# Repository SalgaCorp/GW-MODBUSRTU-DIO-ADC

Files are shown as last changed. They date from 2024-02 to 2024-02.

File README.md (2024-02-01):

GW MODBUS RTU ADC DIGITAL InOut: Open Source

Image of the GW or Node with ESP32 from LILYGO.







View design attachments:

Information document in Spanish

[DOCUMENTO_INFORMATIVO_GATEWAY_MODBUS_v1_06122023.pdf](https://github.com/SalgaCorp/GW-MODBUSRTU-DIO-ADC/files/14130991/DOCUMENTO_INFORMATIVO_GATEWAY_MODBUS_v1_06122023.pdf)

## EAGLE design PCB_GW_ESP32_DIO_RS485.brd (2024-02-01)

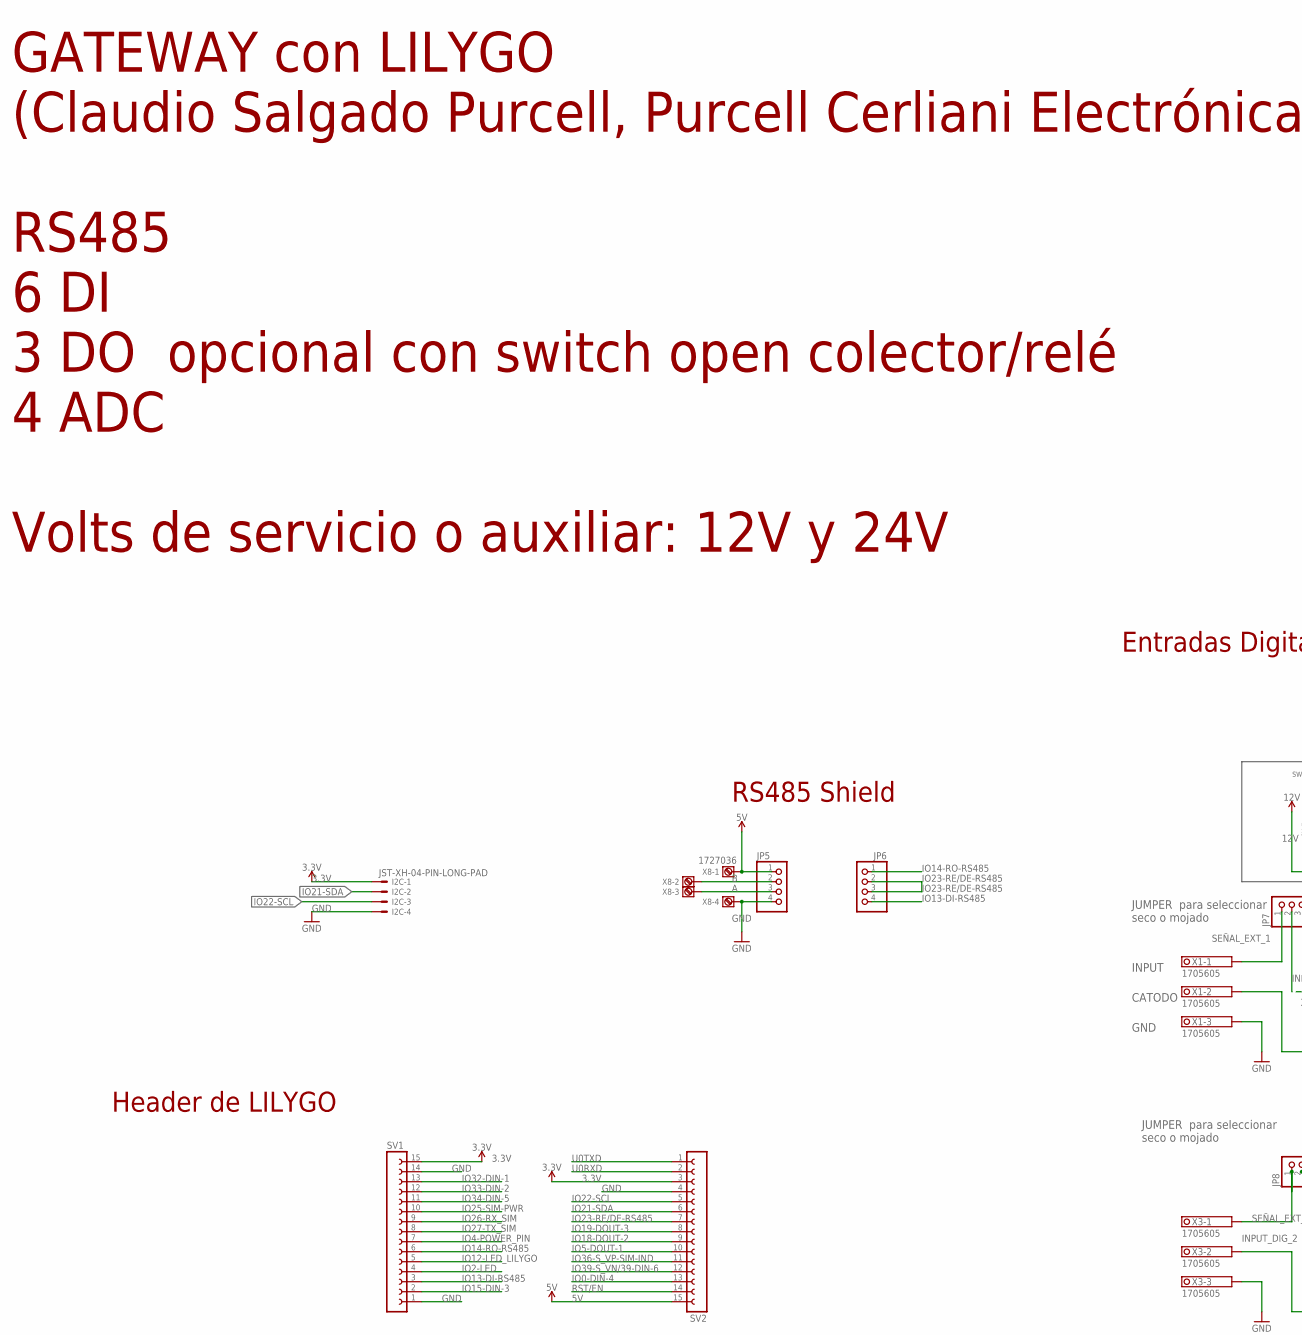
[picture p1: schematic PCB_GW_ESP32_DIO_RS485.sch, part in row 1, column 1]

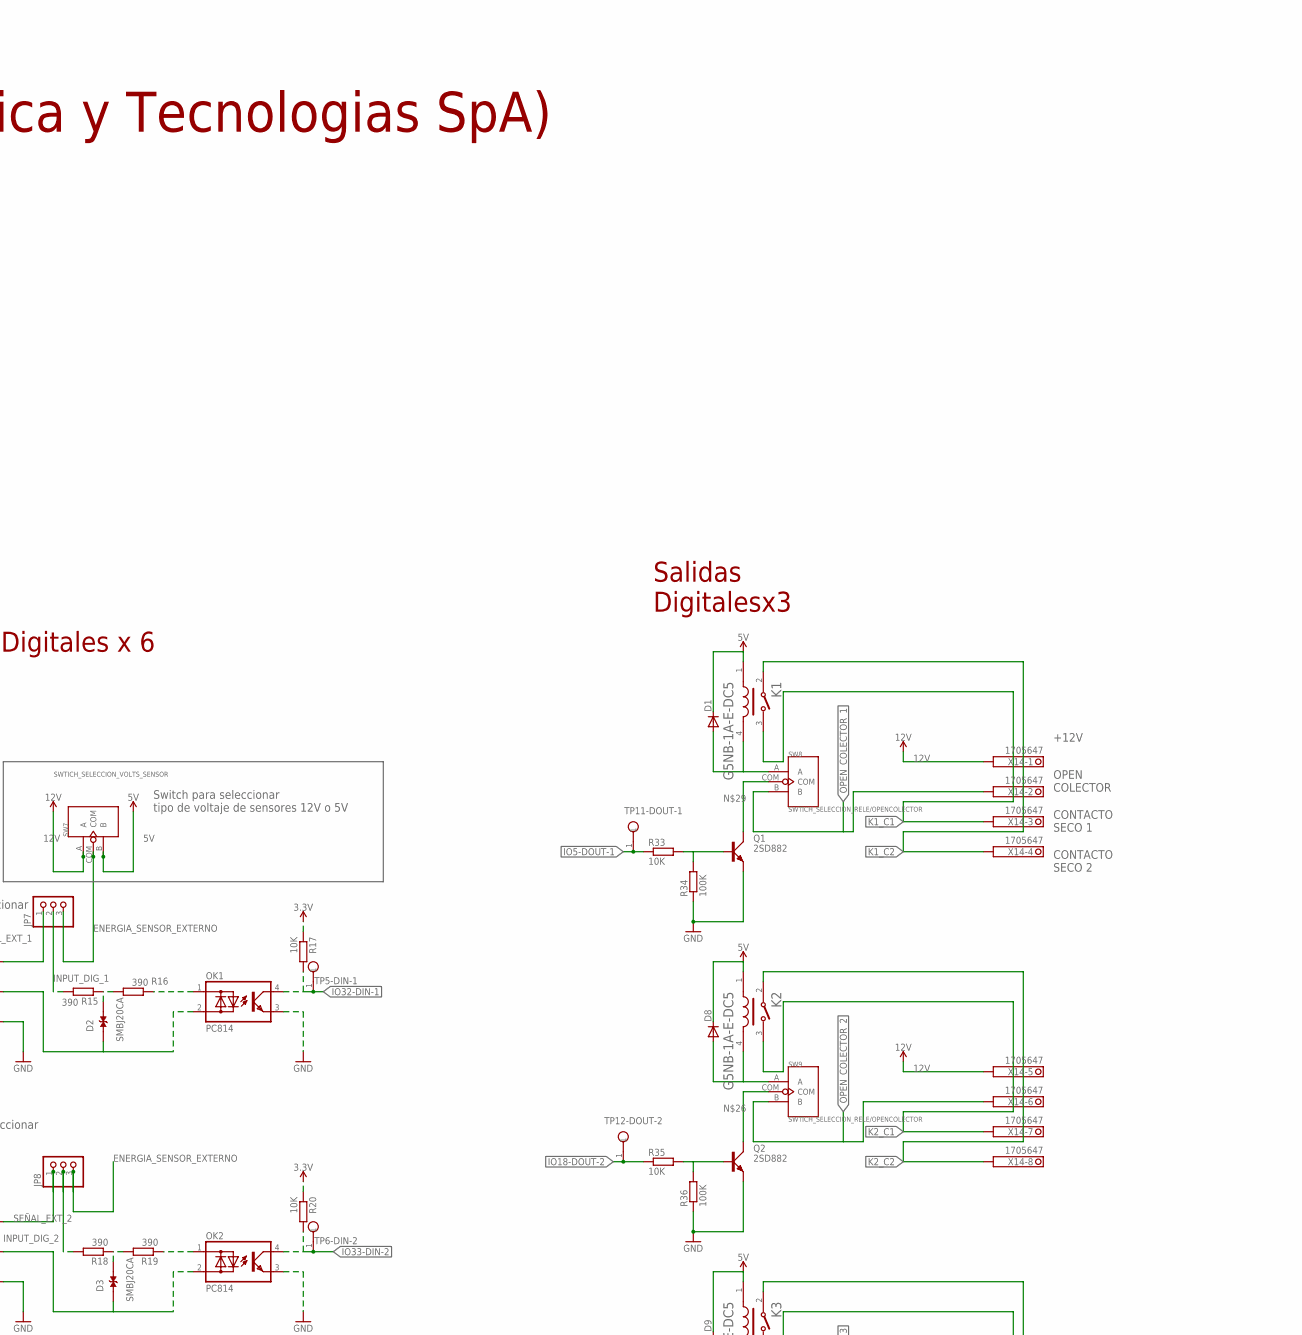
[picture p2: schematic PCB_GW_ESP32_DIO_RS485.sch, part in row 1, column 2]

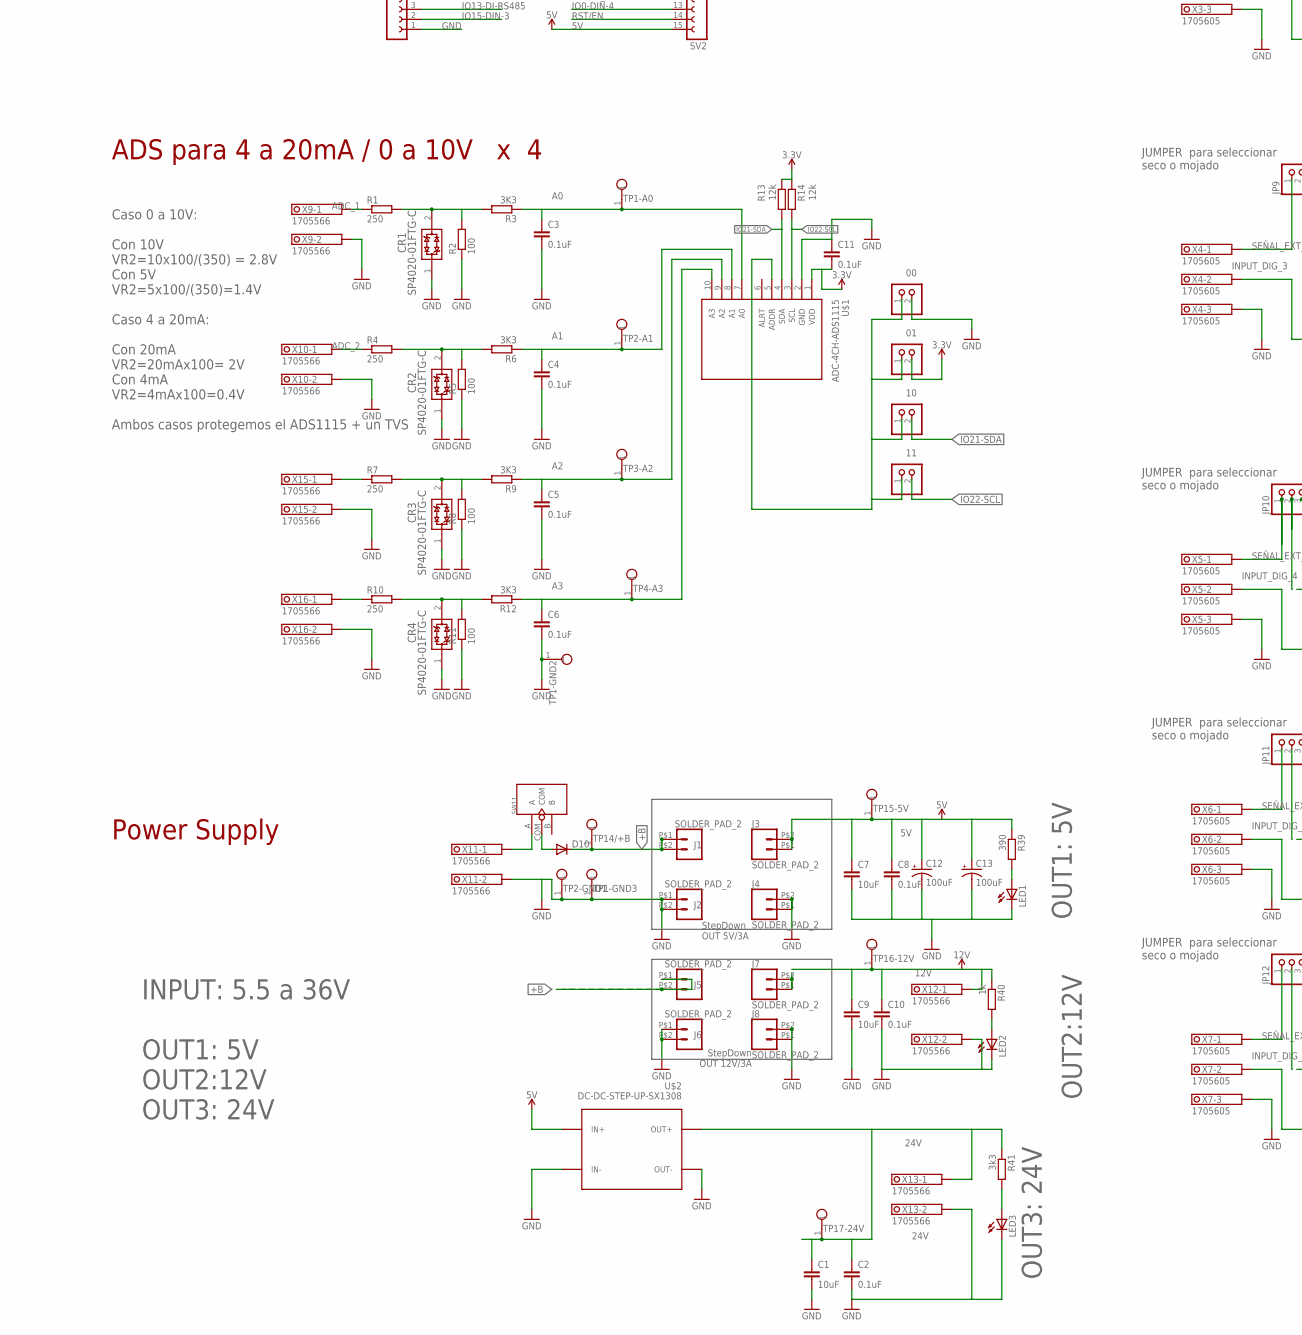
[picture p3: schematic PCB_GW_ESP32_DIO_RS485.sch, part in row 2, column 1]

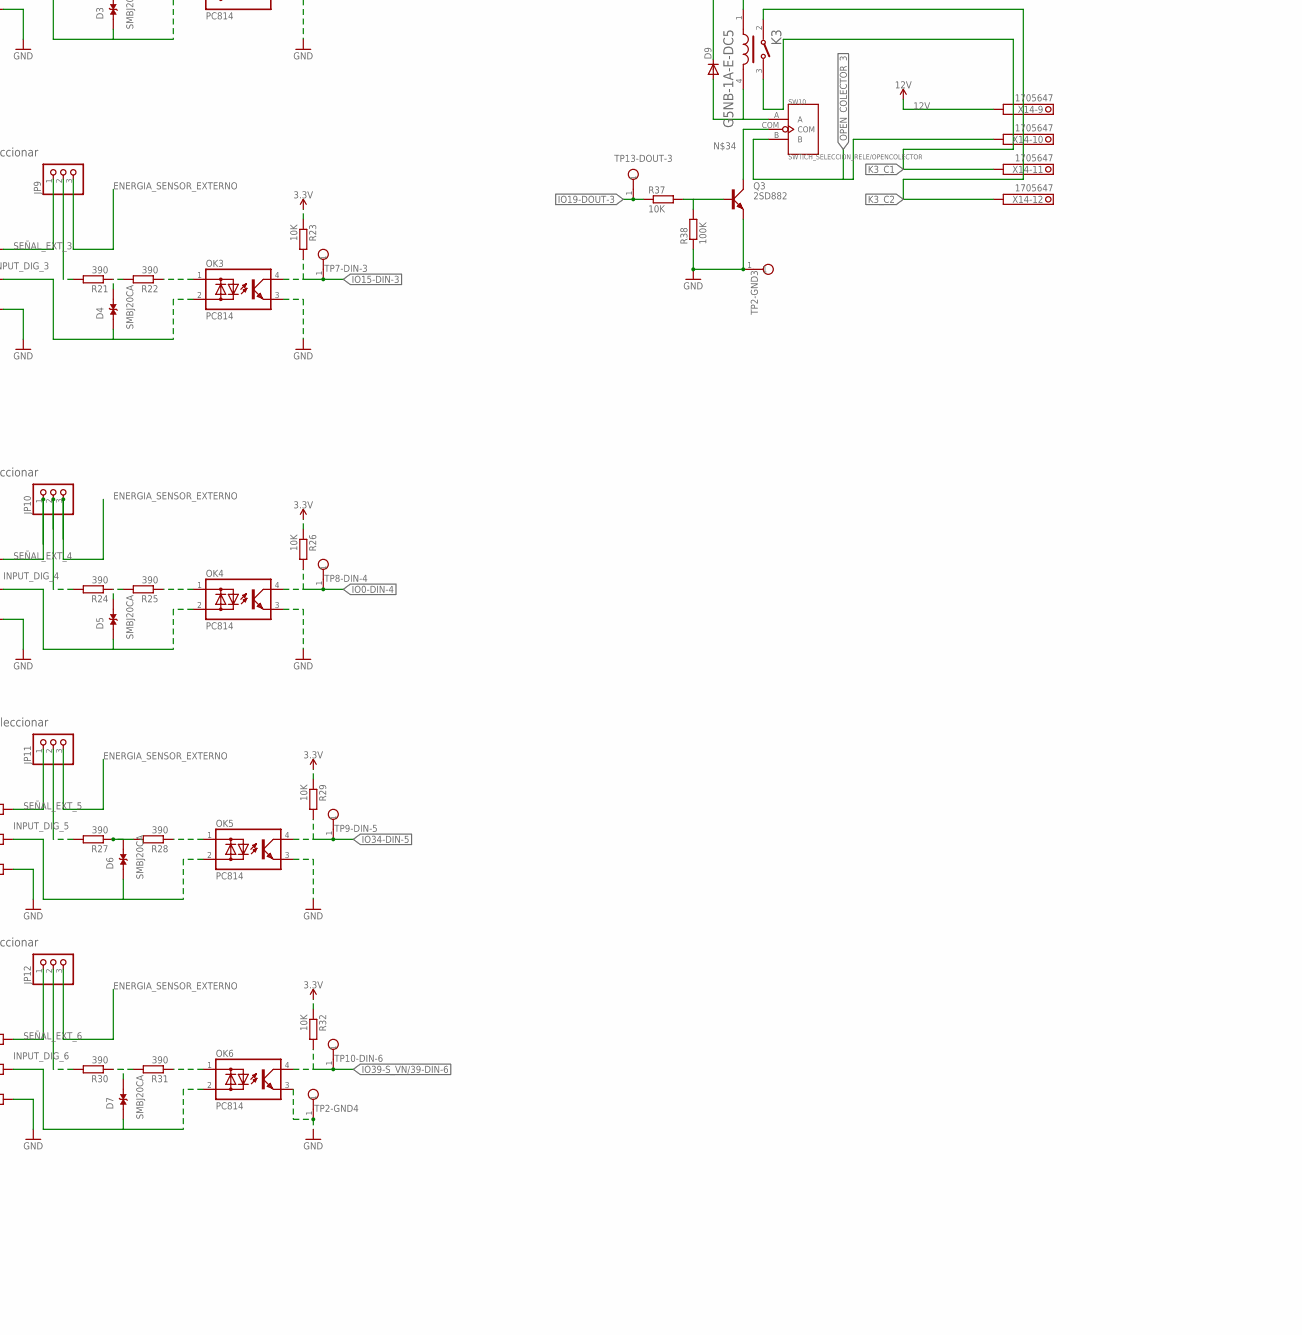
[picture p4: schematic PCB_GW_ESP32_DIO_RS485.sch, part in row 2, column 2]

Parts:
C1, C7, C9: 10uF; 1206
C2, C3, C4, C5, C6, C8, C10, C11: 0.1uF; 1206
C12: 100uF; CPOL-RADIAL-2.5MM-6.5MM
C13: 100uF; PANASONIC_D
CR1, CR2, CR3, CR4: SP4020-01FTG-C; SOD323_LTF
D1, D8, D9, D10: DIODE-DO214AC; DO214AC
D2, D3, D4, D5, D6, D7: SMBJ20CA; DIOM4336X265N
I2C: JST-XH-04-PIN-LONG-PAD; JST-XH-04-PACKAGE-LONG-PAD
J1, J2, J3, J4, J5, J6, J7, J8: SOLDER_PAD_2
JP1: 00; 1X02
JP2: 01; 1X02
JP3: 10; 1X02
JP4: 11; 1X02
JP5, JP6: PINHD-1X4; 1X04
JP7, JP8, JP9, JP10, JP11, JP12: PINHD-1X3; 1X03
K1, K2, K3: OMRON_G5NB-1A-E-DC5OMRON_G5NB-1A-E-DC5_0_0; OMRON_G5NB-1A-E-DC5_0
LED1, LED2, LED3: LEDCHIPLED_1206; CHIPLED_1206
OK1, OK2, OK3, OK4, OK5, OK6: PC814; DIL04
Q1, Q2, Q3: 2SD882; TO126AV
R1, R4, R7, R10: 250; R1206
R2, R5, R8, R11: 100; R1206
R3, R6, R9, R12: 3K3; R1206
R13, R14: 12k; R1206
R15, R16, R18, R19, R21, R22, R24, R25, R27, R28, R30, R31, R39: 390; R1206
R17, R20, R23, R26, R29, R32, R33, R35, R37: 10K; R1206
R34, R36, R38: 100K; R1206
R40: 1k; R1206
R41: 3k3; R1206
SV1, SV2: FE15-1; FE15
SW7: SWTICH_SELECCION_VOLTS_SENSOR; SW5-2.0-8.8X4.4X4.7MM-90D
SW8, SW9, SW10: SWTICH_SELECCION_RELE/OPENCOLECTOR; SW5-2.0-8.8X4.4X4.7MM-90D
SW11: DIP-TOGGLE-SWITCH-ON-ON(3+2P-8.8X4.6MM)-90D; SW5-2.0-8.8X4.4X4.7MM-90D
TP1-A0, TP1-GND2, TP1-GND3, TP2-A1, TP2-GND1, TP2-GND3, TP2-GND4, TP3-A2, TP4-A3, TP5-DIN-1, TP6-DIN-2, TP7-DIN-3, TP8-DIN-4, TP9-DIN-5, TP10-DIN-6, TP11-DOUT-1, TP12-DOUT-2, TP13-DOUT-3, TP14/+B, TP15-5V, TP16-12V, TP17-24V: TESTPOINT
U$1: ADC-4CH-ADS1115
U$2: DC-DC-STEP-UP-SX1308
X1, X3, X4, X5, X6, X7: 1705605
X8: 1727036
X9, X10, X11, X12, X13, X15, X16: 1705566
X14: 1705647

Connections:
3.3V: C11.2, I2C.1, JP2.2, R13.1, R14.1, R17.1, R20.1, R23.1, R26.1, R29.1, R32.1, SV1.15, SV2.3, U$1.1 (VDD)
5V: C7.1, C8.1, C12.1 (+), C13.+, D1.C, D8.C, D9.C, J3.P$1 (1), J3.P$2 (2), JP5.1, K1.1, K2.1, K3.1, R39.1, SV2.15, SW7.B, TP15-5V.1, U$2.IN+, X8.1
12V: C9.1, C10.1, J7.P$1 (1), J7.P$2 (2), R40.1, SW7.A, TP16-12V.1, X12.1.1, X12.1.2, X14.1.1, X14.1.2, X14.5.1, X14.5.2, X14.9.1, X14.9.2
24V: C1.1, C2.1, R41.1, TP17-24V.1, U$2.OUT+, X13.1.1, X13.1.2
+B: D10.C, J1.P$1 (1), J1.P$2 (2), J5.P$1 (1), J5.P$2 (2), TP14/+B.1
A: JP5.3, X8.3
A0: C3.1, R3.1, TP1-A0.1, U$1.7 (A0)
A1: C4.1, R6.1, TP2-A1.1, U$1.8 (A1)
A2: C5.1, R9.1, TP3-A2.1, U$1.9 (A2)
A3: C6.1, R12.1, TP4-A3.1, U$1.10 (A3)
ADC_1: R1.1, X9.1.1, X9.1.2
ADC_2: R4.1, X10.1.1, X10.1.2
ADC_3: R7.1, X15.1.1, X15.1.2
ADC_4: R10.1, X16.1.1, X16.1.2
B: JP5.2, X8.2
ENERGIA_SENSOR_EXTERNO: JP7.3, JP8.3, JP9.3, JP10.3, JP11.3, JP12.3, SW7.COM
GND: C1.2, C2.2, C3.2, C4.2, C5.2, C6.2, C7.2, C8.2, C9.2, C10.2, C11.1, C12.2 (-), C13.-, CR1.1, CR2.1, CR3.1, CR4.1, I2C.4, J2.P$1 (1), J2.P$2 (2), J4.P$1 (1), J4.P$2 (2), J6.P$1 (1), J6.P$2 (2), J8.P$1 (1), J8.P$2 (2), JP1.2, JP5.4, LED1.C, LED2.C, LED3.C, OK1.3 (E), OK2.3 (E), OK3.3 (E), OK4.3 (E), OK5.3 (E), OK6.3 (E), Q1.E, Q2.E, Q3.E, R2.1, R5.1, R8.1, R11.1, R34.1, R36.1, R38.1, SV1.1, SV1.14, SV2.4, TP1-GND2.1, TP1-GND3.1, TP2-GND1.1, TP2-GND3.1, TP2-GND4.1, U$1.2 (GND), U$2.IN-, U$2.OUT-, X1.3.1, X1.3.2, X3.3.1, X3.3.2, X4.3.1, X4.3.2, X5.3.1, X5.3.2, X6.3.1, X6.3.2, X7.3.1, X7.3.2, X8.4, X9.2.1, X9.2.2, X10.2.1, X10.2.2, X11.2.1, X11.2.2, X12.2.1, X12.2.2, X13.2.1, X13.2.2, X15.2.1, X15.2.2, X16.2.1, X16.2.2
INPUT_DIG_1: JP7.2, R15.2
INPUT_DIG_2: JP8.2, R18.2
INPUT_DIG_3: JP9.2, R21.2
INPUT_DIG_4: JP10.2, R24.2
INPUT_DIG_5: JP11.2, R27.2
INPUT_DIG_6: JP12.2, R30.2
IO0-DIN-4: OK4.4 (C), R26.2, SV2.13, TP8-DIN-4.1
IO2-LED: SV1.4
IO4-POWER_PIN: SV1.7
IO5-DOUT-1: R33.1, SV2.10, TP11-DOUT-1.1
IO12-LED_LILYGO: SV1.5
IO13-DI-RS485: JP6.4, SV1.3
IO14-RO-RS485: JP6.1, SV1.6
IO15-DIN-3: OK3.4 (C), R23.2, SV1.2, TP7-DIN-3.1
IO18-DOUT-2: R35.1, SV2.9, TP12-DOUT-2.1
IO19-DOUT-3: R37.1, SV2.8, TP13-DOUT-3.1
IO21-SDA: I2C.2, JP3.2, R13.2, SV2.6, U$1.4 (SDA)
IO22-SCL: I2C.3, JP4.2, R14.2, SV2.5, U$1.3 (SCL)
IO23-RE/DE-RS485: JP6.2, JP6.3, SV2.7
IO25-SIM-PWR: SV1.10
IO26-RX_SIM: SV1.9
IO27-TX_SIM: SV1.8
IO32-DIN-1: OK1.4 (C), R17.2, SV1.13, TP5-DIN-1.1
IO33-DIN-2: OK2.4 (C), R20.2, SV1.12, TP6-DIN-2.1
IO34-DIN-5: OK5.4 (C), R29.2, SV1.11, TP9-DIN-5.1
IO36-S_VP-SIM-IND: SV2.11
IO39-S_VN/39-DIN-6: OK6.4 (C), R32.2, SV2.12, TP10-DIN-6.1
K1_C1: K1.3, X14.3.1, X14.3.2
K1_C2: K1.2, X14.4.1, X14.4.2
K2_C1: K2.3, X14.7.1, X14.7.2
K2_C2: K2.2, X14.8.1, X14.8.2
K3_C1: K3.3, X14.11.1, X14.11.2
K3_C2: K3.2, X14.12.1, X14.12.2
unnamed: LED1.A, R39.2
unnamed: CR2.2, R4.2, R5.2, R6.2
unnamed: CR1.2, R1.2, R2.2, R3.2
unnamed: CR3.2, R7.2, R8.2, R9.2
unnamed: CR4.2, R10.2, R11.2, R12.2
unnamed: JP1.1, JP2.1, JP3.1, JP4.1, U$1.5 (ADDR)
unnamed: OK1.1 (AC1), R16.1
unnamed: D2.2, R15.1, R16.2
unnamed: OK2.1 (AC1), R19.1
unnamed: D3.2, R18.1, R19.2
unnamed: OK3.1 (AC1), R22.1
unnamed: D4.2, R21.1, R22.2
unnamed: OK4.1 (AC1), R25.1
unnamed: D5.2, R24.1, R25.2
unnamed: Q1.B, R33.2, R34.2
unnamed: OK5.1 (AC1), R28.1
unnamed: D6.2, R27.1, R28.2
unnamed: Q2.B, R35.2, R36.2
unnamed: Q2.C, SW9.COM
unnamed: OK6.1 (AC1), R31.1
unnamed: D7.2, R30.1, R31.2
unnamed: Q1.C, SW8.COM
unnamed: D1.A, K1.4, SW8.A
unnamed: D8.A, K2.4, SW9.A
unnamed: D10.A, SW11.COM
unnamed: Q3.B, R37.2, R38.2
unnamed: Q3.C, SW10.COM
unnamed: D9.A, K3.4, SW10.A
unnamed: LED3.A, R41.2
unnamed: LED2.A, R40.2
OPEN_COLECTOR_1: SW8.B, X14.2.1, X14.2.2
OPEN_COLECTOR_2: SW9.B, X14.6.1, X14.6.2
OPEN_COLECTOR_3: SW10.B, X14.10.1, X14.10.2
POWER_IN: SW11.A, X11.1.1, X11.1.2
RST/EN: SV2.14
SEÑAL_EXT_1: JP7.1, X1.1.1, X1.1.2
SEÑAL_EXT_2: JP8.1, X3.1.1, X3.1.2
SEÑAL_EXT_3: JP9.1, X4.1.1, X4.1.2
SEÑAL_EXT_4: JP10.1, X5.1.1, X5.1.2
SEÑAL_EXT_5: JP11.1, X6.1.1, X6.1.2
SEÑAL_EXT_6: JP12.1, X7.1.1, X7.1.2
SPDT1: D2.1, OK1.2 (AC2), X1.2.1, X1.2.2
SPDT2: D3.1, OK2.2 (AC2), X3.2.1, X3.2.2
SPDT3: D4.1, OK3.2 (AC2), X4.2.1, X4.2.2
SPDT4: D5.1, OK4.2 (AC2), X5.2.1, X5.2.2
SPDT5: D6.1, OK5.2 (AC2), X6.2.1, X6.2.2
SPDT6: D7.1, OK6.2 (AC2), X7.2.1, X7.2.2
U0RXD: SV2.2
U0TXD: SV2.1

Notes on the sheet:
Caso 0 a 10V: Con 10V VR2=10x100/(350) = 2.8V Con 5V VR2=5x100/(350)=1.4V Caso 4 a 20mA: Con 20mA VR2=20mAx100= 2V Con 4mA VR2=4mAx100=0.4V Ambos casos protegemos el ADS1115 + un TVS
ADS para 4 a 20mA / 0 a 10V x 4
Header de LILYGO
Entradas Digitales x 6
Salidas Digitalesx3
RS485 Shield
Power Supply
INPUT: 5.5 a 36V OUT1: 5V OUT2:12V OUT3: 24V
StepDown OUT 5V/3A
StepDown OUT 12V/3A
Switch para seleccionar tipo de voltaje de sensores 12V o 5V
JUMPER para seleccionar seco o mojado
OUT1: 5V
OUT2:12V
OUT3: 24V
GATEWAY con LILYGO (Claudio Salgado Purcell, Purcell Cerliani Electrónica y Tecnologias SpA) RS485 6 DI 3 DO opcional con switch open colector/relé 4 ADC Volts de servicio o auxiliar: 12V y 24V
GND
CATODO
INPUT
CONTACTO SECO 2
CONTACTO SECO 1
OPEN COLECTOR
+12V

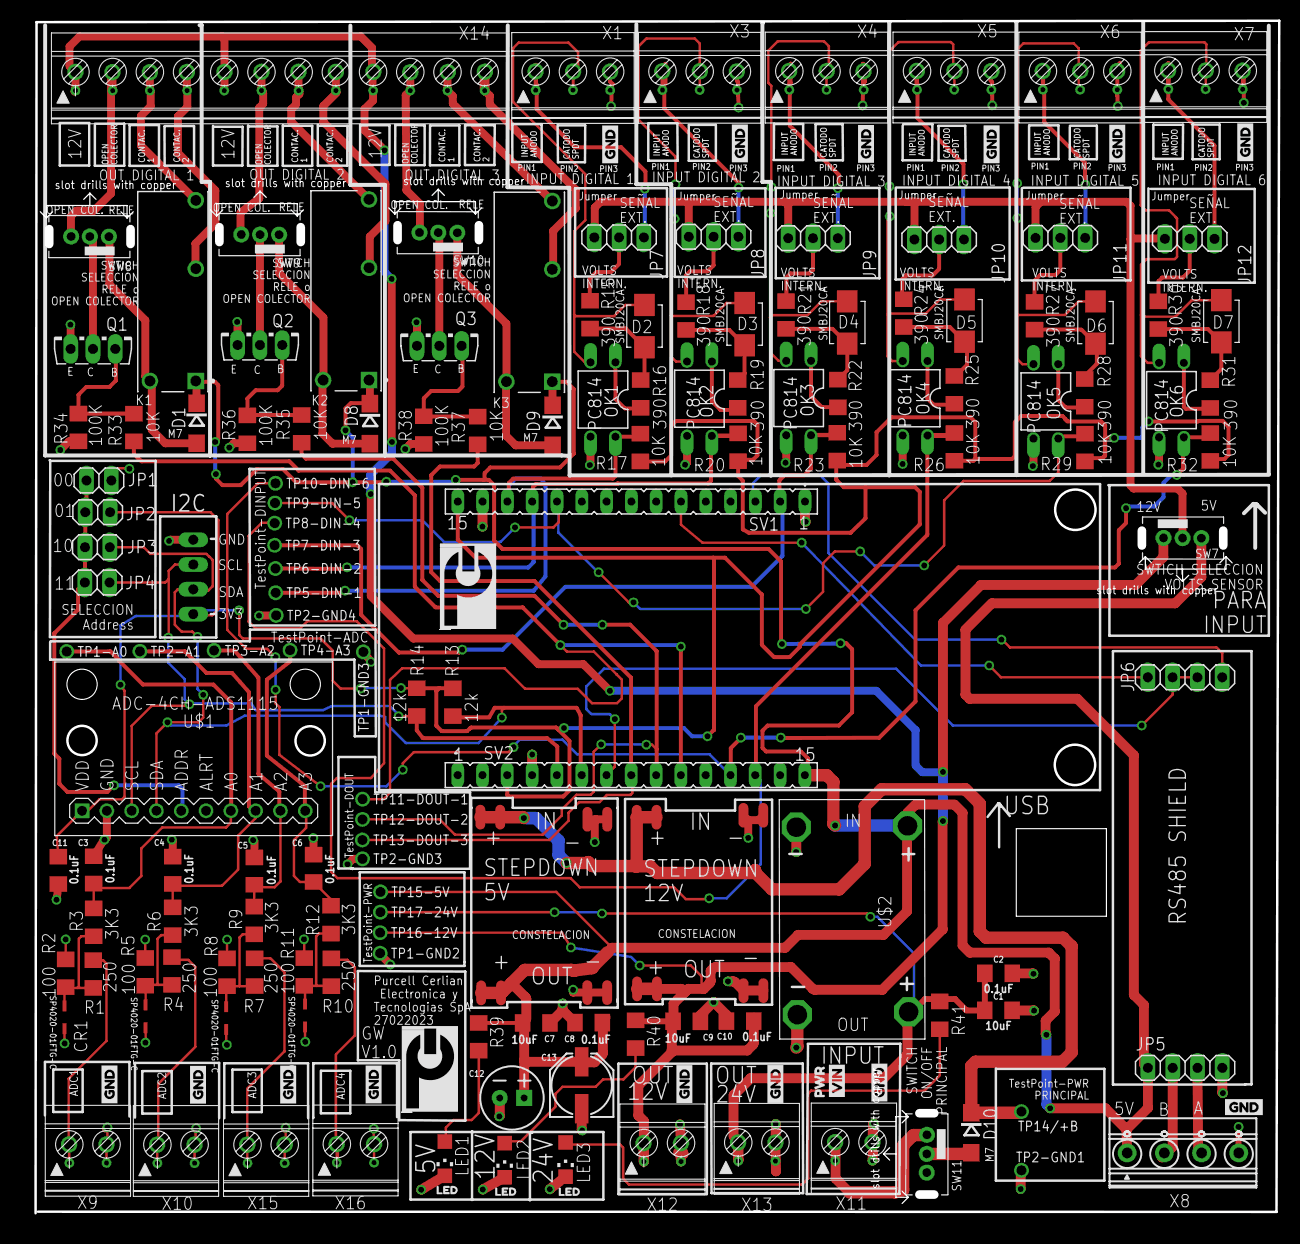
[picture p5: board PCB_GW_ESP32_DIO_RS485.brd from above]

Board: 2 copper layers, 127.4 x 122.1 mm, 169 parts (0 on the bottom side), 89 nets.

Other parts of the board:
U$3: VIN_P
U$4: PWR_TO
U$5, U$6, U$7: LED_TO
U$8, U$9, U$10, U$11, U$12, U$13, U$14, U$15, U$16, U$17, U$18, U$19, U$20, U$21: GND_P

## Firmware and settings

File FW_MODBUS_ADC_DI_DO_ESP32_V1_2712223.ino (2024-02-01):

/*

This code allows validating the operation of the HW, using reading of digital inputs, activation of outputs, reading analog inputs 0 to 3V, reading Modbus RTU data with "ModbusMaster" library.
This code is the basis that the VERDATA client uses to monitor sensors in Modbus RTU.
Created by Claudio PURCELL.
Thanks to :

Author:: Doc Walker (4-20ma@wvfans.net)
Author:: Ag Primatic (agprimatic@gmail.com)
Author:: Marius Kintel (marius@kintel.net)
 */



#include <ModbusMaster.h> //https://github.com/4-20ma/ModbusMaster
#include <SoftwareSerial.h>

#include <Adafruit_ADS1X15.h>

//Adafruit_ADS1115 ads;  /* Use this for the 16-bit version */
Adafruit_ADS1015 ads;     /* Use this for the 12-bit version */
const uint8_t i2c_sda = 21;
const uint8_t i2c_scl = 22;

/*!
  We're using a MAX485-compatible RS485 Transceiver.
  Rx/Tx is hooked up to the hardware serial port at 'Serial'.
  The Data Enable (DE) and Receiver Enable (RE) pins are hooked up as follows:
*/

#define MAX485_RE_NEG  23 //D4 RS485 has a enable/disable pin to transmit or receive data. Arduino Digital Pin 23 = Rx/Tx 'Enable'; High to Transmit, Low to Receive

//SALIDAS control  
//#define RE_DE               23  //GPIO23 IO23       RE_DE
//#define LED_PIN             12  //GPIO12 IO12       LED_EMB


//ENTRADAS DIGITALES
#define DIN1                  32  //GPIO32 IO32       DIN1
#define DIN2                  33  //GPIO33 IO33       DIN2
#define DIN3                  15  //GPIO15 IO15       DIN3
#define DIN4                  00  //GPIO00 IO00       DIN4
#define DIN5                  34  //GPIO34 IO34       DIN5  
#define DIN6                  39  //GPIO39 SENSOR_VN  DIN6   
  
    
//SALIDAS DIGITALES
#define DOUT1               5   //GPIO05 IO05       DOUT1
#define DOUT2               18  //GPIO18 IO18       DOUT2  
#define DOUT3               19  //GPIO19 IO19       DOUT3   
  
int Slave_ID  =     1;
int registro;
int cont=0;
long lastMillis = 0;  
uint8_t result;


SoftwareSerial RS485(14,13); // RX, TX
ModbusMaster node;

void preTransmission()
{
  digitalWrite(MAX485_RE_NEG, HIGH); //Switch to transmit data
}

void postTransmission()
{
  digitalWrite(MAX485_RE_NEG, LOW); //Switch to receive data
}

void setup()
{
    pinMode(MAX485_RE_NEG, OUTPUT);
    // Init in receive mode
    digitalWrite(MAX485_RE_NEG, LOW);
    // // DIGITAL OUTPUTS: control the relays or Open Collector transistors      
    pinMode(DOUT1, OUTPUT);
    pinMode(DOUT2, OUTPUT);
    pinMode(DOUT3, OUTPUT);
    digitalWrite(DOUT1, LOW);
    digitalWrite(DOUT2, LOW);
    digitalWrite(DOUT3, LOW);


    // DIGITAL INPUTS: receive state changes from the optocouplers    
    pinMode(DIN1, INPUT);
    pinMode(DIN2, INPUT);
    pinMode(DIN3, INPUT);
    pinMode(DIN4, INPUT);
    pinMode(DIN5, INPUT);
    pinMode(DIN6, INPUT);


    //Modbus communication runs at 9600 baud
    Serial.begin(9600, SERIAL_8N1);
    RS485.begin(9600);

    Wire.begin(i2c_sda, i2c_scl);
    Serial.println("ADC Range: +/- 6.144V (1 bit = 3mV/ADS1015, 0.1875mV/ADS1115)");

    if (!ads.begin()) {
    Serial.println("Failed to initialize ADS.");
    while (1);
    }
  
    node.begin(Slave_ID, RS485);

    // Callbacks allow us to configure the RS485 transceiver correctly
    node.preTransmission(preTransmission);
    node.postTransmission(postTransmission);
}


void loop() 
{
 
  
  long currentMillis = millis();
  
  if (currentMillis - lastMillis > 3000) 
  {

  cont++;
  if(cont==0){

    digitalWrite(DOUT1, LOW);
    digitalWrite(DOUT2, LOW);
    digitalWrite(DOUT3, LOW);
    }

  if(cont==1){

    digitalWrite(DOUT1, HIGH);
    digitalWrite(DOUT2, LOW);
    digitalWrite(DOUT3, LOW);
    }

  if(cont==2){

    digitalWrite(DOUT1, LOW);
    digitalWrite(DOUT2, HIGH);
    digitalWrite(DOUT3, LOW);
    }

  if(cont==3){

    digitalWrite(DOUT1, LOW);
    digitalWrite(DOUT2, LOW);
    digitalWrite(DOUT3, HIGH);
    cont=0;
    }

    Serial.println();
    Serial.println();
    int DI1 = digitalRead(DIN1);
    int DI2 = digitalRead(DIN2);
    int DI3 = digitalRead(DIN3);
    int DI4 = digitalRead(DIN4);
    int DI5 = digitalRead(DIN5);
    int DI6 = digitalRead(DIN6);

    Serial.print("DIN1: ");
    Serial.print(DI1);
    Serial.print("|| DIN2: ");
    Serial.print(DI2);
    Serial.print("|| DIN3: ");
    Serial.print(DI3);
    Serial.print("|| DIN4: ");
    Serial.print(DI4);
    Serial.print("|| DIN5: ");
    Serial.print(DI5);
    Serial.print("|| DIN6: ");
    Serial.print(DI6);
    Serial.println();
    Serial.println(); 
    
    int DO1 = digitalRead(DOUT1);
    int DO2 = digitalRead(DOUT2);
    int DO3 = digitalRead(DOUT3);
     
    Serial.print("DOUT1: ");
    Serial.print(DO1);
    Serial.print("|| DOUT2: ");
    Serial.print(DO2);
    Serial.print("|| DOUT3: ");
    Serial.print(DO3);
    
    Serial.println();
    Serial.println(); 

    int16_t adc0, adc1, adc2, adc3;
    float volts0, volts1, volts2, volts3;

    adc0 = ads.readADC_SingleEnded(0);
    adc1 = ads.readADC_SingleEnded(1);
    adc2 = ads.readADC_SingleEnded(2);
    adc3 = ads.readADC_SingleEnded(3);
  
    volts0 = ads.computeVolts(adc0);
    volts1 = ads.computeVolts(adc1);
    volts2 = ads.computeVolts(adc2);
    volts3 = ads.computeVolts(adc3);
  


    Serial.println("-----------------------------------------------------------");
    Serial.println("ADC ADS1115)");
    Serial.print("AIN0: "); Serial.print(adc0); Serial.print(" , "); Serial.print(volts0); Serial.print("V");
    Serial.print("||  AIN1: "); Serial.print(adc1); Serial.print(" , "); Serial.print(volts1); Serial.print("V");
    Serial.print("||  AIN2: "); Serial.print(adc2); Serial.print(" , "); Serial.print(volts2); Serial.print("V");
    Serial.print("||  AIN3: "); Serial.print(adc3); Serial.print(" , "); Serial.print(volts3); Serial.println("V");

    result = node.readInputRegisters(0, 8);

    if (result == node.ku8MBSuccess) {
      
      int ADC1 = node.getResponseBuffer(0x00);
      Serial.print("ADC1: ");
      Serial.println(ADC1);

      int ADC2 = node.getResponseBuffer(0x01);
      Serial.print("ADC2: ");
      Serial.println(ADC2);

      int ADC3 = node.getResponseBuffer(0x02);
      Serial.print("ADC3: ");
      Serial.println(ADC3);

      int ADC4 = node.getResponseBuffer(0x03);
      Serial.print("ADC4: ");
      Serial.println(ADC4);

      int ADC5 = node.getResponseBuffer(0x04);
      Serial.print("ADC5: ");
      Serial.println(ADC5);

      int ADC6 = node.getResponseBuffer(0x05);
      Serial.print("ADC6: ");
      Serial.println(ADC6);

      int ADC7 = node.getResponseBuffer(0x06);
      Serial.print("ADC7: ");
      Serial.println(ADC7);

      int ADC8 = node.getResponseBuffer(0x07);
      Serial.print("ADC8: ");
      Serial.println(ADC8);
      }

    Serial.println("");
    Serial.println("");

    //reading MODBUS RTU device ID from an ADAM HW
    result = node.readHoldingRegisters(0x00F7, 2);
    
    if (result == node.ku8MBSuccess) {
      int ID = node.getResponseBuffer(0x00);
      Serial.print("ID: ");
      Serial.println(ID);
      Serial.println("");
      } 
    
    else {
      // update of status failed
      Serial.println("Lectura MODBUS RTU falla o sin conexión!");
      }
    lastMillis = currentMillis;
  }
}

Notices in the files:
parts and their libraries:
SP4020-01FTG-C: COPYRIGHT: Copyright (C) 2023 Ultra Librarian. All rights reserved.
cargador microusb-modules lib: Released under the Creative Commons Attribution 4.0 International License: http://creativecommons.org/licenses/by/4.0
